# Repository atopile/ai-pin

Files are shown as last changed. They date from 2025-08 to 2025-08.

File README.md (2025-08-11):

## AI Pin — Your private, wearable memory

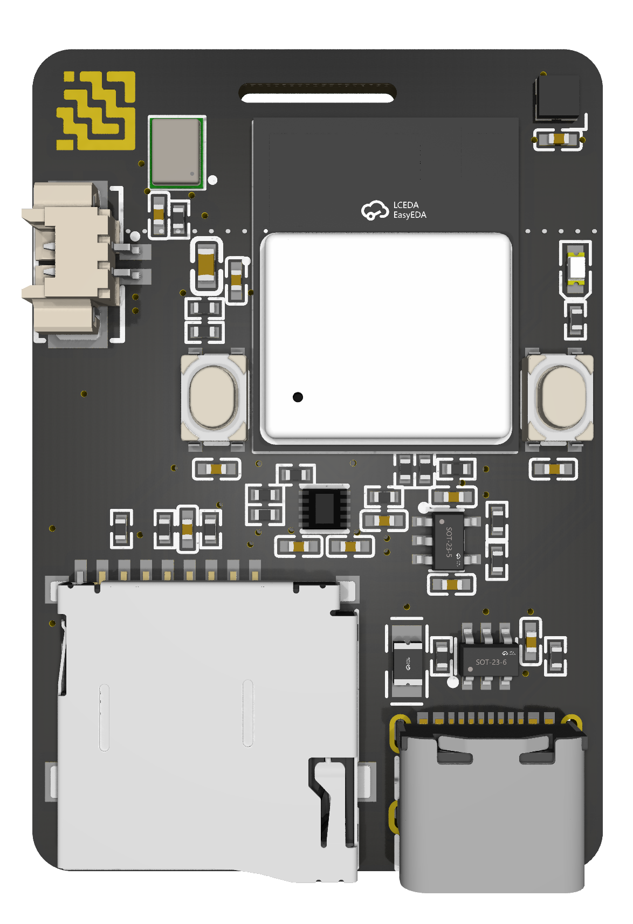
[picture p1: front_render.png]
AI Pin front render


**Stop forgetting what matters.** AI Pin is a privacy‑first wearable that captures your conversations throughout the day, then—when you’re home—offloads to your own local server to transcribe and make everything searchable. Ask, “What did I promise Alex yesterday?” or “What did I get done today?” and get instant answers from your own life.

### Why this is different

- **AI‑designed hardware**: The PCB is designed using `atopile` (a declarative electronics DSL) and lives as code in `ai-pin.ato`.
- **Local‑first by default**: All storage, transcription, embeddings and search run on your own machine—no cloud or third‑party services.
- **End‑to‑end system**: Wearable capture → local ingestion → Whisper transcription → vector search → Q&A and daily summaries.

### What it does

- **Continuous or on‑demand capture** via an I2S MEMS mic, storing audio on microSD.
- **Nightly offload** over Wi‑Fi while charging to a local server (Docker Compose).
- **Local transcription** using Whisper (GPU if available, CPU fallback).
- **Search & recall** across transcripts with semantic + keyword search.
- **Daily digest** of your day’s conversations and key moments.

### Moments you’ll stop forgetting

- “What did I promise to follow up on in today’s meeting?”
- “Who did I meet at the event—and what did we agree to do next?”
- “Which book/podcast did Sam recommend at lunch?”
- “What were the price, dates, and address the contractor mentioned?”
- “Where did we leave off on that debugging thread last week?”
- “What did the coach say about pickup changes for tomorrow?”
- “What’s the Wi‑Fi password/door code they told me?”
- “What exact phrasing did I use when I committed to that deliverable?”
- “What were the three ideas I said I’d write down later?”

---

## Architecture

```mermaid
graph TD
  Wearable["ESP32‑C3 AI Pin<br/>I2S mic → microSD (WAV)"] -->|Wi‑Fi offload| API[FastAPI Ingestion]
  API --> MINIO[(MinIO Object Storage)]
  API --> REDIS[(Redis Queue)]
  REDIS --> WORKER[Whisper Worker]
  MINIO --> WORKER
  WORKER --> MINIO
  WORKER --> DB[(Postgres + pgvector)]
  UI[Search & Daily Digest UI] --> API
  API --> DB
```

### Processing flow (upload → answer)

```mermaid
sequenceDiagram
    participant Dev as Device
    participant API as Ingestion API
    participant S3 as MinIO
    participant Q as Redis Queue
    participant W as Whisper Worker
    participant DB as Postgres/pgvector

    Dev->>API: POST /v1/upload (WAV)
    API->>S3: putObject(wav)
    API->>Q: enqueue({ key, device_id })
    W-->>Q: blpop()
    Q-->>W: { key, device_id }
    W->>S3: getObject(wav)
    W->>W: transcribe (Whisper)
    W->>S3: putObject(txt/json)
    W->>DB: upsert chunks + embeddings
    Note over W,DB: hybrid index: BM25 + vector
    UI->>API: /v1/search?q=...&time=...
    API->>DB: retrieve + rank
    API-->>UI: results/snippets
```

### Hardware (designed in code)

- MCU: ESP32‑C3 Mini‑1 (`I2S`, `SPI`, `Wi‑Fi`)
- Mic: TDK InvenSense ICS‑43434 (digital I2S)
- Storage: microSD over SPI
- Power: USB‑C → BQ25185 charger/power‑path → LDO (3.3 V)
- Battery: LP402535 (configurable)

See `ai-pin.ato` for the complete, declarative hardware design.

### Firmware (Zephyr RTOS)

- I2S capture → ring buffer → WAV writer (5–10 min segments)
- FATFS on SPI microSD, crash‑safe finalize, sidecar metadata
- Wi‑Fi offload window while charging; TLS upload
- Simple UX: LED states and a single button

### Local backend (Docker Compose)

- Ingestion API (FastAPI)
- Object storage (MinIO)
- Database (Postgres + pgvector)
- Queue (Redis)
- Transcription worker (Whisper via `faster-whisper`)

---

## Agents and your private history

You can point a local agent at your private transcripts to answer questions and automate tasks—without sending data to the cloud.

- **Local‑only by default**: Retrieval happens against your local DB/object store. No outbound calls unless you enable them.
- **Hybrid retrieval**: BM25 + vector search with time filters and device/user scoping.
- **Defensive prompts**: The API returns citations and timestamps; agents are encouraged to include them in answers.

Planned Agent API (local):

- `GET /v1/search` – hybrid search over transcripts
- `POST /v1/agents/query` – higher‑level query that returns stitched context windows for LLMs
- `POST /v1/agents/sessions` – create a scoped session with time/person/topic constraints

Example (planned) search call:

```bash
curl "http://localhost:8080/v1/search?q=what+did+I+promise+Alex&from=2025-01-01&to=2025-01-31&top_k=10"
```

Privacy boundaries:

- Local network only; bind to loopback or LAN per your `.env`.
- API tokens for agent clients; optional mTLS.
- Audit log of queries; per‑user/device scoping.
- Optional redaction layer (emails, credit cards) before indexing.

---

## Quickstart

### 1) Start the local stack

Create `backend/compose/.env` with these defaults (edit as needed):

```env
API_HOST=0.0.0.0
API_PORT=8080

MINIO_ENDPOINT=minio:9000
MINIO_ACCESS_KEY=minio
MINIO_SECRET_KEY=minio12345
MINIO_SECURE=false
MINIO_BUCKET=aipin

REDIS_URL=redis://redis:6379/0
WHISPER_MODEL=small
WHISPER_COMPUTE_TYPE=auto
```

Then launch:

```bash
cd backend/compose
docker compose up -d
```

Services:

- API: `http://localhost:8080`
- MinIO console: `http://localhost:9001` (user: `minio`, pass: `minio12345`)
- Postgres: `localhost:5432`
- Redis: `localhost:6379`

Health check:

```bash
curl http://localhost:8080/healthz
```

### 2) Upload a sample WAV (simulating the device)

```bash
curl -X POST \
  -F "device_id=test-device" \
  -F "file=@/path/to/sample.wav;type=audio/wav" \
  http://localhost:8080/v1/upload
```

The worker will pick it up, transcribe, and write a `.txt` next to the `.wav` in MinIO.

---

## Developing the firmware (ESP32‑C3 + Zephyr)

See detailed instructions in `firmware/zephyr/README.md`. Quickstart:

Prereqs (one‑time):

```bash
/opt/homebrew/bin/python3 -m venv "$HOME/zephyr-venv"
source "$HOME/zephyr-venv/bin/activate"
pip install -U pip west
cd "$HOME/zephyrproject"
export ZEPHYR_SDK_INSTALL_DIR="$HOME/zephyr-sdk-0.17.2"
export ZEPHYR_TOOLCHAIN_VARIANT=zephyr
west zephyr-export
```

Build & flash:

```bash
source "$HOME/zephyr-venv/bin/activate"
cd "$HOME/zephyrproject"
west build -b esp32c3_devkitm $(pwd -P)/../projects/ai-pin/firmware/zephyr/app -p always -- \
  -DDTC_OVERLAY_FILE=boards/esp32c3_devkitm.overlay \
  -DPython3_EXECUTABLE="$HOME/zephyr-venv/bin/python" -DWEST_PYTHON="$HOME/zephyr-venv/bin/python"
west flash
```

Provision Wi‑Fi on SD card (root):

```ini
ssid=YOUR_SSID
psk=YOUR_PASSWORD
```

Troubleshooting highlights:

- Missing blobs for ESP32: `west blobs fetch hal_espressif`
- I2S DMA error: ensure overlay enables `&dma { status = "okay"; }` and `&i2s { dmas = <&dma 0>, <&dma 1>; }`, and `CONFIG_DMA=y` in `prj.conf`
- CMake can’t find west: pass venv python flags shown above

---

## Project status

- Hardware captured in `ai-pin.ato` (Atopile)
- Backend Compose stack scaffolded: API + MinIO + Postgres + Redis + Whisper worker
- Firmware stubs prepared (Zephyr app structure)

See `spec.md` and `todo.md` for detailed scope, milestones, and open questions.

---

## Roadmap (MVP highlights)

- End‑to‑end ingest → transcribe
- Daily summary generation
- OTA updates via MCUboot
- Optional SD encryption and mTLS device identity

---

## Contributing

Issues and PRs welcome. The goal is a great local‑first reference design for private, wearable memory.

---

## License

MIT

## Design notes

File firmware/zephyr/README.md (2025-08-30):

# Firmware (Zephyr, ESP32‑C3)

This directory will contain the Zephyr application for the AI Pin firmware.

Quickstart

- Ensure you have a Zephyr workspace (e.g., `~/zephyrproject`) and Zephyr SDK installed (e.g., `~/zephyr-sdk-0.17.2`).
- This app targets ESP32‑C3 DevKitM and uses a device‑tree overlay to enable I2S and SPI SD (CS on GPIO4).

Environment setup (recommended once)

```
# Create/use a Python venv for west/cmake integration
/opt/homebrew/bin/python3 -m venv "$HOME/zephyr-venv"
source "$HOME/zephyr-venv/bin/activate"
pip install -U pip west

# Use your Zephyr workspace and SDK
cd "$HOME/zephyrproject"
export ZEPHYR_SDK_INSTALL_DIR="$HOME/zephyr-sdk-0.17.2"
export ZEPHYR_TOOLCHAIN_VARIANT=zephyr
west zephyr-export
```

Build

```
source "$HOME/zephyr-venv/bin/activate"
cd "$HOME/zephyrproject"
west build -b esp32c3_devkitm /Users/nicholaskrstevski/github/ai_pin/firmware/zephyr/app -p always -- \
  -DDTC_OVERLAY_FILE=boards/esp32c3_devkitm.overlay
```

Flash

```
west flash
```

Notes

- `prj.conf` enables I2S, SPI, FATFS, Wi‑Fi, Logging, and Settings. DMA is enabled for I2S.
- `boards/esp32c3_devkitm.overlay` maps SPI microSD CS to GPIO4 and enables I2S (`&i2s`). Update MOSI/MISO/SCLK to match your board.
- Wi‑Fi provisioning: copy `firmware/zephyr/wifi.txt.example` to the SD card root and rename to `wifi.txt`:
  - `ssid=YourNetwork`
  - `psk=YourPassword`
    The firmware reads `/SD:/wifi.txt` at boot and attempts to connect.

Troubleshooting

- If build fails to find west from CMake: pass the venv python
  - Add to the build command tail: `-DPython3_EXECUTABLE="$HOME/zephyr-venv/bin/python" -DWEST_PYTHON="$HOME/zephyr-venv/bin/python"`
- If blobs missing for ESP32: run `west blobs fetch hal_espressif` in `~/zephyrproject`.
- If you see "DMA peripheral is not enabled!" from I2S: ensure `CONFIG_DMA=y` and `CONFIG_DMA_ESP32=y` are set in `prj.conf`.
- For FatFS volume errors: use `zephyr,sdhc-spi-slot` with `mmc { compatible = "zephyr,sdmmc-disk"; }` in the overlay. Avoid hard‑coding `FS_FATFS_VOLUME_STRS` in `prj.conf`.

Run & monitor

- UART 115200‑8‑N‑1. Example: `screen /dev/tty.usbserial* 115200`
- Expected boot logs:
  - `AI Pin firmware (Zephyr) booting`
  - SD: `Mounted FAT at /SD:` (when card present)
  - Wi‑Fi: `Read Wi‑Fi credentials ...` then `Got IPv4 address`

Testing checklist (abridged)

- Build & flash: no immediate errors on boot
- Audio: no persistent I2S errors; ring overflows rare at idle
- Storage: `.wav` files in SD root; valid PCM S16LE @ 16kHz; rotation works
- Wi‑Fi: connects using `/SD:/wifi.txt` and obtains IPv4 address

## Monitoring serial output

Use one of the following options to view logs at 115200 baud.

Option A: west monitor (recommended if west is in your venv PATH)

```
source "$HOME/zephyr-venv/bin/activate"
cd "$HOME/zephyrproject"
west espressif monitor -p /dev/cu.usbmodem1101 -b 115200
# Quit with: Ctrl-]
```

Option B: Python miniterm (no west required)

```
python -m serial.tools.miniterm /dev/cu.usbmodem1101 115200
# Quit with: Ctrl-]
```

Option C: screen (preinstalled on macOS)

```
screen /dev/cu.usbmodem1101 115200
# Quit with: Ctrl-A then K, then Y
```

## Troubleshooting serial

- If you see only ROM boot messages and no Zephyr logs, the port may be reset into bootloader. Try another app that does not toggle DTR/RTS, such as miniterm or screen.
- If `west` is not found, ensure your venv is active: `source "$HOME/zephyr-venv/bin/activate"` and that west is installed: `pip install -U west` then `west --version`.
- To list ports: `ls /dev/cu.*` and pick the `usbmodem` (ESP32-C3 USB CDC) device.

## Expected boot logs

- `AI Pin firmware (Zephyr) booting`
- `Mounted FAT at /SD:` once the SD card is detected
- `Read Wi‑Fi credentials ...` then `Got IPv4 address` on successful Wi‑Fi

## Pinout (current build)

Note: Console is routed to on‑chip USB CDC; I2S is currently disabled to avoid SPI2 pin conflicts.

| Function | GPIO | Notes |
| --- | --- | --- |
| LED (red) | 20 | Active‑high heartbeat |
| Addressable LED (SK6805/WS2812) | 21 | Data‑in |
| SPI2 SCLK | 6 | Board `spim2_default` |
| SPI2 MOSI | 7 | Board `spim2_default` |
| SPI2 MISO | 2 | Board `spim2_default` |
| microSD CS | 4 | Active‑low (overlay `cs-gpios`)  |
| Console | USB CDC | `&usb_serial` (no external pins) |

## I2S mapping (disabled)

If I2S is enabled on this board configuration, pins map as:

- I2S MCLK: GPIO6
- I2S WS/LRCLK: GPIO5
- I2S BCLK: GPIO4
- I2S SD Out (to DAC): GPIO18
- I2S SD In (from mic): GPIO19

Conflict note: I2S BCLK on GPIO4 conflicts with the SD CS on GPIO4, and MCLK on GPIO6 conflicts with SPI2 SCLK on GPIO6. That’s why I2S is disabled in the current overlay.

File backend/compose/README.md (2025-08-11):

# Backend – Local testing guide

Start services

```bash
cd /Users/narayanpowderly/projects/ai-pin/backend/compose
docker compose up -d --build
docker compose ps
docker compose logs -f api worker
```

Health check

```bash
curl http://localhost:8080/healthz
```

Prepare test audio

- Convert MP3 to 16 kHz mono WAV (recommended):

```bash
ffmpeg -i /path/to/song.mp3 -ar 16000 -ac 1 /tmp/test.wav
```

- Or generate a 5s tone:

```bash
ffmpeg -f lavfi -i "sine=frequency=1000:duration=5" -ar 16000 -ac 1 /tmp/test.wav
```

Upload file to API

- WAV:

```bash
curl -X POST \
  -F "file=@/tmp/test.wav;type=audio/wav" \
  -F "device_id=dev123" \
  http://localhost:8080/v1/upload
```

- MP3:

```bash
curl -X POST \
  -F "file=@/path/to/song.mp3;type=audio/mpeg" \
  -F "device_id=dev123" \
  http://localhost:8080/v1/upload
```

Watch transcription progress

```bash
docker compose logs -f worker
```

Inspect artifacts in MinIO

- Console: http://localhost:9001 (user: `minio`, pass: `minio12345`), bucket: `aipin`
- With AWS CLI:

```bash
export AWS_ACCESS_KEY_ID=minio
export AWS_SECRET_ACCESS_KEY=minio12345
aws --endpoint-url http://localhost:9000 s3 ls s3://aipin/ --recursive
# Download transcript (replace KEY):
aws --endpoint-url http://localhost:9000 s3 cp s3://aipin/KEY .
```

Troubleshooting

```bash
docker compose ps
docker compose logs api
docker compose restart api
```

- Re-run upload and tail worker logs:

```bash
docker compose logs -f worker
```

Stop services

```bash
docker compose down
```

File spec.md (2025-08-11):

## AI Pin – Product & Technical Specification

### Summary

- Wearable device that captures audio throughout the day, stores locally on microSD, and offloads via Wi‑Fi to a private, user‑hosted server while charging. The local server transcribes audio to text with Whisper and makes it searchable for questions like “What did I get done today?”.

### Goals

- Reliable audio capture with minimal user interaction
- Nightly/private offload and transcription
- Local‑first: all data and processing live on the user’s own machine/NAS/server (no cloud dependency)
- Searchable, privacy‑respecting archive with daily summaries

### Non‑Goals (initially)

- On‑device transcription (server‑side only)
- Cellular connectivity
- Complex display/UI (stick to LED/haptics/buttons)

---

## Hardware (current design per `ai-pin.ato`)

### Bill of Materials (logical)

- MCU/Radio: `ESP32_C3_MINI_1_driver` (ESP32‑C3 module)
- USB Power/Connector: `USB2_0TypeCHorizontalConnector`
- Charger/Power Path: `BQ25185_driver`
- Primary Regulators: `LDK220M_R` (LDO to 3.3 V)
- Battery: `EMB_BATTERY_LP402535_driver` (configured 300 mAh)
- Microphone: `TDK_InvenSense_ICS_43434` (digital I2S MEMS MIC)
- Storage: `MicroSDCardAssemblyWithRemovableSPI` (microSD over SPI, CS on `mcu.gpio[4]`)
- I2C: pull‑ups 10 kΩ (0402) to `power_3v3`

### Power Topology

- `usb_c.usb.usb_if.buspower` → `power_vbus_5v`
- `power_vbus_5v` → `charger.power_vbus`
- Battery rail: `battery.power` ↔ `power_batt` ↔ `charger.power_batt`
- System rail: `charger.power_sys` → `LDK220M_R` → `power_3v3` (asserted 2.97–3.15 V)
- Loads: `mcu.power`, `mic.power`, `microsd.power` tied to `power_3v3`

### Digital Interfaces

- Audio: `mcu.i2s ~ mic.i2s`
- Storage: `mcu.spi ~ microsd.spi`, `mcu.gpio[4] ~ microsd.spi_cs`
- I2C: pull‑ups to 3.3 V; `mcu.i2c.sda.reference.hv ~> R ~> mcu.i2c.sda.line` and same for SCL

### Notes & Risks

- ESP32‑C3 performance/pins are sufficient for SPI microSD + I2S mic recording to WAV; consider throughput testing and SD card class requirements.
- Unresolved package imports currently reported by the toolchain; see “Ato package checklist”.

### Ato package checklist (to install)

- `atopile/espressif-esp32-c3/esp32_c3_mini.ato`
- `atopile/usb-connectors/usb-connectors.ato`
- `atopile/st-ldk220/st-ldk220.ato`
- `atopile/microphones/tdk_invensense_ics_43434.ato`
- `atopile/ti-bq25185/ti-bq25185.ato`
- `atopile/sd-card/sd-card-slots.ato`
- `atopile/batteries/eemb_battery_lp402535.ato`

---

## Firmware (ESP32‑C3, Zephyr RTOS)

### Core Features

- Audio capture via Zephyr I2S API → ring buffer → WAV chunking
- File I/O to SPI microSD using Zephyr `fs` (FATFS) with safe rotation and metadata sidecars
- Wi‑Fi provisioning and nightly offload to a local server with TLS (mTLS optional)
- LED/haptics/button UX for recording, charging, syncing, errors
- Power management (charger state, low‑battery shutdown)
- OTA update via MCUboot (image management with mcumgr over BLE/Wi‑Fi or HTTP OTA)

### Concurrency Model

- Zephyr threads and work queues
- Audio thread: configure I2S, optional VAD, double‑buffer
- Storage thread: consume buffers, write `.wav`, fsync, rotate N minutes
- Uploader thread: Wi‑Fi connect, scan for pending files, resume, checksum verify
- Power management: charger/ADC polling, battery state, thermal guardrails
- Provisioning: BLE or SoftAP captive portal; credentials via Zephyr Settings subsystem
- LED/UI: state machine driving RGB LED patterns; debounced button via Zephyr input APIs

### File/Format

- WAV PCM mono, 16 kHz, 16‑bit (Whisper friendly)
- Segment duration: 5–10 min; filename includes RTC + monotonic seq
- Sidecar JSON per file: { timestamp range, dropped frames, battery %, gain, sw/hw versions }

### Reliability & Security

- Preallocation/atomic rename on close; journal index for recovery
- Backpressure policy: pause capture if SD stalls; telemetry counter
- TLS 1.2+ to server; optional per‑file encryption (ChaCha20‑Poly1305) with device key stored via Zephyr Settings (and optional hardware keying later)

### UX Mapping (proposed)

- Button: short press start/stop recording; long press enters provisioning/sync
- LED: recording (solid red), idle (dim cyan), uploading (blue pulse), charging (amber), full (green), error (red blink), mute (magenta)
- Optional haptic buzz on state change

---

## Offload & Backend (Local‑first)

### Ingestion

- Authenticated upload endpoint (token or mTLS) hosted on the user’s machine/NAS/server. Supports resumable uploads and metadata posting.
- Stores raw audio + sidecars to local object storage (MinIO):
  - `users/{userId}/devices/{deviceId}/{YYYY}/{MM}/{DD}/{HHmmss}_{seq}.wav`
  - matching `.json` and `.txt` (post‑transcription)

### Processing

- Local queue per uploaded file (e.g., Redis)
- Local transcription workers using Whisper (e.g., `faster-whisper`). Language auto‑detect; VAD prepass to skip silence. No cloud services required.
- Post‑processing: sentence boundary alignment, optional diarization, timestamps

### Storage & Search

- Local Postgres for metadata and transcripts (JSONB per chunk)
- Local pgvector for embeddings; alternatives: local Qdrant/Milvus if scale dictates
- RAG pipeline: hybrid search (BM25 + vector) with time filters and user constraints

### Query UX

- Daily digest: “What did I get done today?” generated from that day’s transcripts
- Free‑form Q&A over selected time ranges

### Security & Privacy (backend)

- LAN‑only by default (no Internet egress needed); optional remote access via user‑managed reverse proxy/VPN
- TLS everywhere; encrypted local volumes; MinIO with server‑side encryption; per‑user isolation
- Audit logging; retention controls; deletion handling
- Optional PII redaction pass on transcripts

### Local deployment

- Provide a `docker-compose.yml` that brings up: API (FastAPI/Express), MinIO, Postgres (+pgvector), Redis, and a Whisper worker (GPU‑accelerated if available; CPU fallback)
- mDNS for local discovery; device posts to `https://ai-pin.local` (configurable)

### Agents & Private History

Local agents can query transcripts to answer questions and automate tasks without leaving your machine.

#### Retrieval model

- Hybrid search: BM25 + vector with reciprocal rank fusion; time and device filters
- Chunking: sentence or ~512‑token windows with overlap; store timestamps per chunk
- Embeddings: local model (e.g., `bge-small-en`) stored in pgvector; optional Qdrant/Milvus at scale

#### Agent sessions & scopes

- Session object defines time window, people/topics (optional), device/user scope, and privacy level
- Responses include citations (file key, start/end timestamps) for traceability
- Redaction profile can be applied per session before returning text to agents

#### Agent API (planned)

- `GET /v1/search` – hybrid search over transcripts with filters and `top_k`
- `POST /v1/agents/query` – returns stitched context windows for LLMs plus citations
- `POST /v1/agents/sessions` – create session with scope and redaction policy; returns `session_id`

#### Data model additions (planned)

- `agent_sessions(id, user_id, created_at, scope_json, redaction_profile)`
- `search_logs(id, session_id?, query, filters_json, top_k, latency_ms, created_at)`

#### Privacy & security defaults

- Bind API to loopback or LAN; no egress by default
- PAT or mTLS for agent clients; per‑user isolation
- Optional PII redaction before indexing and/or at query time
- Retention policies and deletion propagate to vector store and MinIO

---

## Data Model (sketch)

### Objects

- Audio: `.wav` in object storage; sidecars `.json`; transcripts `.txt` or JSON

### Database (Postgres)

- `users(id, email, created_at, ...)`
- `devices(id, user_id, model, public_key?, created_at, ...)`
- `files(id, device_id, path, start_ts, end_ts, duration_s, size_bytes, checksum, status, created_at)`
- `transcript_chunks(id, file_id, start_ms, end_ms, text, confidence, speaker?)`
- `embeddings(id, chunk_id, vector, model, created_at)`
- `jobs(id, type, status, payload, created_at, updated_at)`

---

## Security & Provisioning

- Device identity: token provisioned via BLE/SoftAP portal; optional per‑device cert (mTLS)
- On‑device keys via Zephyr Settings; secure boot/flash encryption can be enabled in later revisions
- SD at‑rest encryption optional (configurable per user)

---

## Milestones

- v0 Bench Prototype
  - ESP32‑C3 dev board + I2S mic + SPI microSD
  - Record WAV, manual Wi‑Fi upload, basic server endpoint
- v1 MVP Wearable
  - Custom PCB (this design), nightly offload, server transcription, searchable UI, OTA
- v2 Reliability/Privacy
  - Encryption at rest, device provisioning flow, improved power telemetry
- v3 UX & ML
  - Advanced Q&A, diarization, mobile companion app

---

## Acceptance Criteria (MVP)

- 8+ hours of continuous recording on 300 mAh battery or clear segmented/on‑demand mode documented
- <1% dropped audio frames per hour on a Class 10 microSD (specified test card)
- Nightly offload completes for a full day’s data over WPA2 network with retry
- End‑to‑end transcription and searchable queries over last 7 days
- OTA update succeeds and is roll‑back safe

---

## Implementation Options & Trade‑offs

- Mic: I2S MEMS (simple, low BOM) vs analog mic + codec (higher fidelity, more power/complexity)
- SD: SPI (fewer pins, slower) vs SDMMC 4‑bit (faster, more pins)
- Encryption: on‑device per‑file (privacy, CPU/battery cost) vs server‑only
- Provisioning: BLE (mobile‑friendly) vs SoftAP (no app, clunkier UX)
- Vector store: pgvector (simple ops) vs Qdrant/Milvus (scale)

---

## Open Questions

### Hardware

- Keep ESP32‑C3 or upgrade to S3 for USB‑OTG and more I2S headroom?
- Confirm ICS‑43434 mic orientation/porting and mechanical acoustics (wind/noise filters)?
- SPI microSD performance: required write throughput, target SD class, acceptable latency spikes?
- Include a fuel gauge (e.g., MAX17048) for better battery UX, or estimate via voltage?
- Add hardware mute switch for mic? LED behavior when muted?
- Charging LED behaviors and power‑path current limits for record‑while‑charge?

### Firmware

- Continuous recording vs VAD‑triggered segments to save space/power?
- Segment length: 5 vs 10 minutes vs silence‑aligned segments?
- On‑device file encryption from day one or later?
- Provisioning method: BLE vs SoftAP; do we ship a mobile app?
- Minimum acceptable dropped‑frame rate under worst‑case SD latency?
- Exact LED/haptic state machine definitions and timeouts?

### Backend/ML

- Transcription: Whisper locally (`faster-whisper`, choose model size per hardware); target accuracy vs local compute constraints?
- Embeddings: local (`bge-small-en` or similar) vs hosted; default is local‑only
- Vector DB: pgvector vs Qdrant/Milvus; expected daily transcript volume and 1‑year scale?
- PII handling/redaction requirements and default retention window?
- Query UX: chat‑style vs daily digest first; which user interfaces (web/mobile)?

### Security/Operations

- Device auth: token vs mTLS; key rotation strategy?
- SD at‑rest encryption: key provisioning, backup, and device‑loss UX?
- Wi‑Fi credential rotation and multi‑SSID support?
- OTA cadence, staged rollout, and failure recovery policy?

---

## Test Plan (high level)

- Throughput: validate continuous write of 16‑kHz 16‑bit mono WAV with <1% drops over 8 h
- Power: measure battery life in continuous vs VAD modes; thermals while charging + recording
- Filesystem: abrupt power‑loss tests; index recovery; file integrity checksums
- Networking: upload retries, resume support, checksum verification; TLS certificate validation to local server
- Backend: local queue backlog handling, transcription latency, accuracy sampling; measure CPU/GPU utilization
- Search: relevance on benchmark queries; time‑range filters; daily digest quality

---

## Next Steps

- Resolve Ato package imports and build PCB draft (hardware is largely done)
- Scaffold Zephyr application (I2S capture, FATFS on SPI SD, Wi‑Fi manager, TLS uploader, LED/button, Zephyr Settings)
- Create `docker-compose.yml` for local stack (API, MinIO, Postgres+pgvector, Redis, Whisper worker)
- Implement ingestion API and local Whisper worker
- Minimal web UI for daily summaries and free‑form questions

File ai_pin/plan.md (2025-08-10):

# AI Pin PCBA – Planning Document

This plan outlines the architecture, chosen packages, and key design decisions for an ESP32-C3 based “AI pin” with an I2S microphone, microSD storage, LiPo battery power with USB‑C charging, and a regulated 3.1 V rail for the MCU.

## Goals and constraints
- ESP32‑C3 microcontroller as main MCU
- Digital microphone for voice commands (I2S preferred)
- External microSD card for audio storage (SPI interface)
- Battery powered (single‑cell LiPo)
- USB‑C for charging and power
- Power path: either battery or USB 5 V feeds an LDO set to 3.1 V to supply the ESP32
- Follow `@.cursor/rules/how_to_build_packages.mdc`; use registry packages; build must be error‑free
- Do NOT implement code yet; this file is the plan to review before implementation

## Selected atopile packages (registry)
- MCU: `atopile/espressif-esp32-c3@0.1.4`
  - Use `ESP32_C3_MINI_1_driver` (compact module, good community support)
  - Provides `power`, `i2c`, `spi`, `i2s`, `gpio[N]` interfaces; example pin mux in README
- Microphone: `atopile/microphones@0.2.0`
  - Pick I2S mic: `TDK_InvenSense_ICS_43434`
  - Supply 1.62–3.6 V (OK at 3.1 V)
- microSD card: `atopile/sd-card@0.1.6` + socket `atopile/sd-card-slots@0.1.4`
  - Use SPI mode with ESP32‑C3 `spi` interface
  - VDD 2.7–3.6 V; 3.1 V is within spec
- USB‑C connector: `atopile/usb-connectors@0.3.0`
  - Use `USB2_0TypeCHorizontal_driver` (or vertical if preferred)
  - Exposes VBUS and USB2.0 D+/D- if needed
- Charger with power‑path: `atopile/ti-bq25185@0.1.0`
  - Single‑cell Li‑ion charger with power path; I2C control/status
  - Input from USB‑C VBUS; battery to BAT; system rail from charger goes to LDO input
- LDO (adjustable to 3.1 V): `atopile/st-ldk220@0.2.1`
  - 200 mA low‑IQ LDO; input up to 13.2 V; dropout 100–350 mV
  - Configure output via assertion to 3.1 V (+/‑ 5%)

## Power architecture
- `power_vbus_5v`: from USB‑C VBUS (5 V)
- `power_batt`: single‑cell LiPo (nominal ~3.7 V; 3.0–4.2 V range)
- `charger_power_path_out`: system rail from `BQ25185` (sourced from VBUS or battery via charger’s power path)
- `power_3v1`: LDO output set to 3.1 V (feeds logic and MCU)

Connections (conceptual):
- USB‑C VBUS → BQ25185 VIN
- LiPo (via 2‑pin battery connector, see below) → BQ25185 BAT
- BQ25185 system/power‑path output → LDK220M_R input
- LDK220M_R output (3.1 V) → ESP32‑C3 power, microphone power, microSD VDD, I2C pull‑ups, etc.

Notes:
- 3.1 V is chosen to reduce MCU power while keeping peripherals in spec (microSD 2.7–3.6 V, I2S mic 1.62–3.6 V)
- If battery drops below (3.1 V + LDO dropout), rail will fall out of regulation; plan brown‑out threshold accordingly in firmware

## Interfaces and routing
- I2S Microphone
  - `i2s ~ microphone.i2s`
  - Route `i2s.ws`, `i2s.sck`, `i2s.sd` per ESP32‑C3 pin mux (see driver README example)
  - Mic power from 3.1 V
- microSD over SPI
  - `spi ~ sd.spi` and one GPIO for `cs`
  - VDD from 3.1 V; ensure adequate decoupling and short traces
  - Consider small series resistors (22–33 Ω) on SPI lines if needed (SI integrity)
- I2C bus (for charger config/telemetry; optional other sensors later)
  - `i2c ~ charger.i2c`
  - Add pull‑ups to 3.1 V (10 kΩ 0402 typical); the ESP32‑C3 example shows a pattern for this
- USB data (optional)
  - If desired for CDC/DFU, connect USB D+/D- from connector to MCU USB interface (ESP32‑C3 supports native USB‑CDC on some SKUs). Not strictly required for MVP; serial flashing also possible via UART.

## Connectors and passives
- Battery connector: JST‑PH‑2 (2.0 mm) or JST‑SH‑2 (1.0 mm) for compactness
  - If no registry package exists, use a simple 2‑pin connector package later; wire to BQ25185 BAT/GND
- Power rail decoupling
  - Follow each package recommendations; ensure local 100 nF near each IC, plus bulk caps near LDO output and charger input
- Pull‑ups / bias
  - I2C: 2× 10 kΩ to 3.1 V (SDA/SCL)
  - Charger: check BQ25185 pin requirements (ILIM, STAT, EN, thermistor/NTC). Driver likely models these; otherwise add passives per datasheet.

## Current budget (rough)
- ESP32‑C3 active wifi/BT: 80–240 mA peaks (depends on mode)
- I2S mic: a few mA
- microSD active write: 50–100 mA peaks
- LDO LDK220 limit: 200 mA — Risk: may be insufficient during simultaneous Wi‑Fi peaks + SD activity
  - Mitigations:
    - Reduce RF TX power / duty cycling
    - Switch to higher‑current LDO if needed (alternative regulator TBD)
    - Use local bulk capacitance on 3.1 V rail to absorb transients

## Software‑visible constraints
- Run ESP32 at 3.1 V; ensure brown‑out detector set appropriately (~2.9–3.0 V)
- SPI clock to SD tuned for stable operation at 3.1 V and board trace lengths
- I2S sample rate and mic gain set in firmware
- Charger configuration via I2C: set charge current per chosen battery and USB constraints

## Open questions / risks
- LDO headroom vs. ESP32 + SD peaks: 200 mA may be tight → be ready to swap for higher‑current LDO if needed
- Exact ESP32‑C3 module variant (Mini‑1 vs WROOM‑02): Mini‑1 is planned; verify antenna keepout and footprint
- Battery selection and connector footprint (capacity, discharge rate)
- microSD slot mechanical choice (push‑push vs push‑pull; top vs bottom mount)
- Do we expose USB D+/D- to ESP32 for CDC/flashing?
- BQ25185 details: confirm the driver’s power‑path output node to use for the LDO input; validate NTC/ILIM pins handling

## Implementation plan (after approval)
1. Create `ai_pin/ai-pin.ato` top‑level module
2. Install packages:
   - `atopile add atopile/espressif-esp32-c3`
   - `atopile add atopile/microphones`
   - `atopile add atopile/sd-card`
   - `atopile add atopile/sd-card-slots`
   - `atopile add atopile/usb-connectors`
   - `atopile add atopile/ti-bq25185`
   - `atopile add atopile/st-ldk220`
3. Wire power tree: USB‑C → BQ25185 → LDO → 3.1 V rail → loads
4. Wire I2S mic, SPI SD, I2C to charger; add pull‑ups
5. Add decoupling caps per package guidance
6. Build and resolve compiler/LSP issues; iterate on pin mux and constraints
7. Review DRC/ERC; refine footprints and mechanical choices

## Acceptance checklist prior to coding
- Package set agreed
- 3.1 V rail confirmed acceptable for ESP32, mic, and SD
- Current budget acceptable or alternative LDO identified
- Decision on USB data connectivity
- Battery capacity and connector style chosen

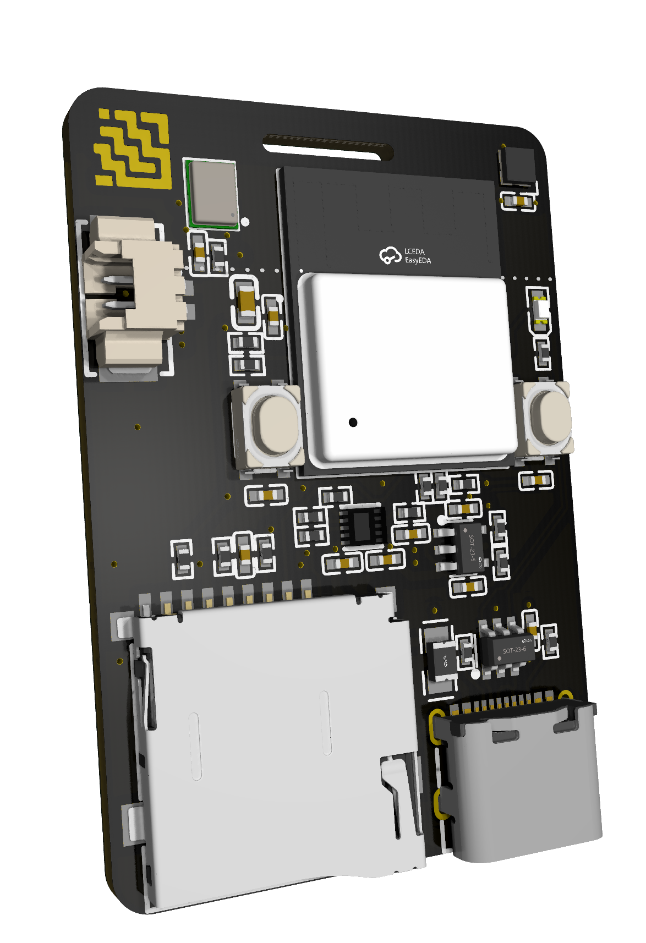
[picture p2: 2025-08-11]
tilt_render.png

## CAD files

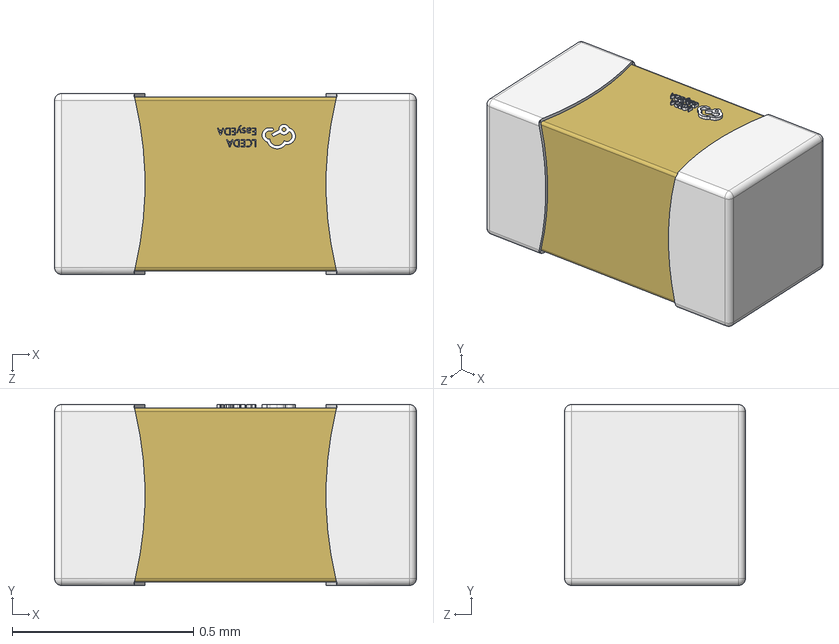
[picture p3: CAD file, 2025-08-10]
parts/Murata_Electronics_GRM155R60J106ME44D/C0402_L1.0-W0.5-H0.5.step
1.00 x 0.5 x 0.5 mm

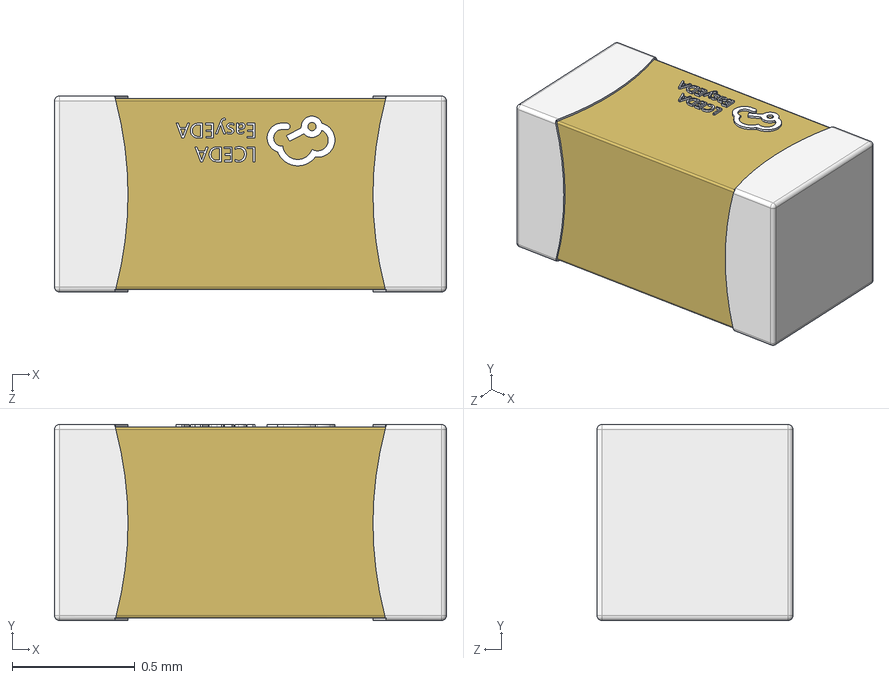
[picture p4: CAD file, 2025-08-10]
parts/Samsung_Electro_Mechanics_CL10A226MQ8NRNC/C0603_L1.6-W0.8-H0.8.step
1.60 x 0.8 x 0.8 mm

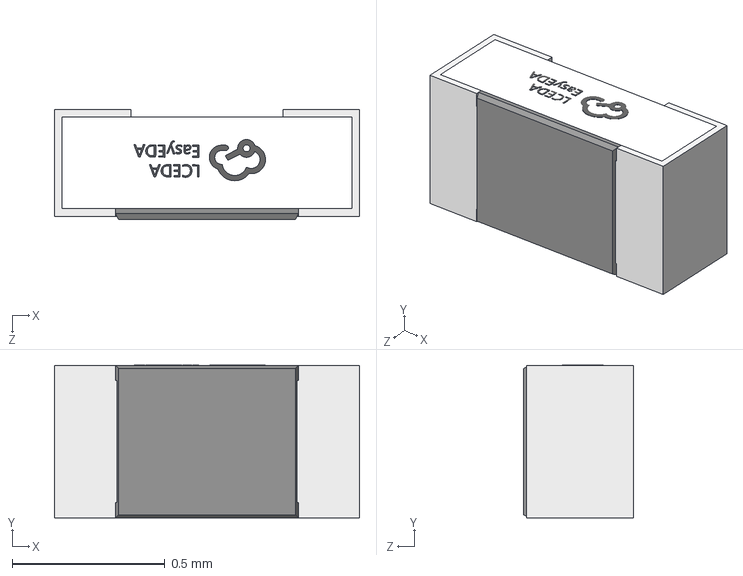
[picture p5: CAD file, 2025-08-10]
parts/YAGEO_RC0402FR_076K2L/R0402_L1.0-W0.5-H0.4.step
1.00 x 0.501 x 0.36 mm

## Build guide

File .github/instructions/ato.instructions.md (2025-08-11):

---
description: ato is a declarative DSL to design electronics (PCBs) with.
applyTo: *.ato, ato.yaml
---

ato is a declarative DSL to design electronics (PCBs) with.
It is part of the atopile project.
Atopile is run by the vscode/cursor/windsurf extension.
The CLI (which is invoked by the extension) actually builds the project.

# Not available in ato

- if statements
- while loops
- functions (calls or definitions)
- classes
- objects
- exceptions
- generators

# Ato Syntax

ato sytax is heavily inspired by Python, but fully declarative.
ato thus has no procedural code, and no side effects.

## Examples of syntax

```ato
#pragma text
#pragma func("X")
# enable for loop syntax feature:
#pragma experiment("FOR_LOOP)

# --- Imports ---
# Standard import (newline terminated)
import ModuleName

# Import with multiple modules (newline terminated)
import Module1, Module2.Submodule

# Import from a specific file/source (newline terminated)
from "path/to/source.ato" import SpecificModule

# Multiple imports on one line (semicolon separated)
import AnotherModule; from "another/source.ato" import AnotherSpecific

# Deprecated import form (newline terminated)
# TODO: remove when unsupported
import DeprecatedModule from "other/source.ato"

# --- Top-level Definitions and Statements ---

pass
pass;

"docstring-like statement"
"docstring-like statement";

top_level_var = 123

# Compound statement
pass; another_var = 456; "another docstring"

# Block definitions
component MyComponent:
    # Simple statement inside block (newline terminated)
    pass

    # Multiple simple statements on one line (semicolon separated)
    pass; internal_flag = True

module AnotherBaseModule:
    pin base_pin
    base_param = 10

interface MyInterface:
    pin io

module DemoModule from AnotherBaseModule:
    # --- Declarations ---
    pin p1              # Pin declaration with name
    pin 1               # Pin declaration with number
    pin "GND"           # Pin declaration with string
    signal my_signal    # Signal definition
    a_field: AnotherBaseModule      # Field declaration with type hint

    # --- Assignments ---
    # Newline terminated:
    internal_variable = 123

    # Semicolon separated on one line:
    var_a = 1; var_b = "string"

    # Cumulative assignment (+=, -=) - Newline terminated
    value = 1
    value += 1; value -= 1

    # Set assignment (|=, &=) - Newline terminated
    flags |= 1; flags &= 2

    # --- Connections ---
    p1 ~ base_pin
    mif ~> bridge
    mif ~> bridge ~> bridge
    mif ~> bridge ~> bridge ~> mif
    bridge ~> mif
    mif <~ bridge
    mif <~ bridge <~ bridge
    mif <~ bridge <~ bridge <~ mif
    bridge <~ mif

    # Semicolon separated on one line:
    p_multi1 ~ my_signal; p_multi2 ~ sig_multi1

    # --- Retyping ---
    instance.x -> AnotherBaseModule

    # --- Instantiation ---
    instance = new MyComponent
    container = new MyComponent[10]
    templated_instance_a = new MyComponent
    templated_instance_b = new MyComponent<int_=1>
    templated_instance_c = new MyComponent<float_=2.5>
    templated_instance_d = new MyComponent<string_="hello">
    templated_instance_e = new MyComponent<int_=1, float_=2.5, string_="hello">
    templated_instance_f = new MyComponent<int_=1, float_=2.5, string_="hello", bool_=True>

    # Semicolon separated instantiations (via assignment):
    inst_a = new MyComponent; inst_b = new AnotherBaseModule

    # --- Traits ---
    trait trait_name
    trait trait_name<int_=1>
    trait trait_name<float_=2.5>
    trait trait_name<string_="hello">
    trait trait_name<bool_=True>
    trait trait_name::constructor
    trait trait_name::constructor<int_=1>

    # Semicolon separated on one line:
    trait TraitA; trait TraitB::constructor; trait TraitC<arg_=1>

    # --- Assertions ---
    assert x > 5V
    assert x < 10V
    assert 5V < x < 10V
    assert x >= 5V
    assert x <= 10V
    assert current within 1A +/- 10mA
    assert voltage within 1V +/- 10%
    assert resistance is 1kohm to 1.1kohm

    # Semicolon separated on one line:
    assert x is 1V; assert another_param is 2V

    # --- Loops ---
    for item in container:
        item ~ p1

    # For loop iterating over a slice
    for item in container[0:4]:
        pass
        item.value = 1; pass

    # For loop iterating over a list literal of field references
    for ref in [p1, x.1, x.GND]:
        pass

    # --- References and Indexing ---
    # Reference with array index assignment
    array_element = container[3]

    # --- Literals and Expressions ---
    # Integer
    int_val = 100
    neg_int_val = -50
    hex_val = 0xF1
    bin_val = 0b10
    oct_val = 0o10
    # Float
    float_val = 3.14
    # Physical quantities
    voltage: V = 5V
    resistance: ohm = 10kohm
    capacitance: F = 100nF
    # Bilateral tolerance
    tolerance_val = 1kohm +/- 10%
    tolerance_abs = 5V +/- 500mV
    tolerance_explicit_unit = 10A +/- 1A
    # Bounded quantity (range)
    voltage_range = 3V to 3.6V
    # Boolean
    is_enabled = True
    is_active = False
    # String
    message = "Hello inside module"

    # Arithmetic expressions
    sum_val = 1 + 2
    diff_val = 10 - 3ohm
    prod_val = 5 * 2mA
    div_val = 10V / 2kohm # Results in current
    power_val = 2**3
    complex_expr = (5 + 3) * 2 - 1
    flag_check = state | MASK_VALUE

    # Comparisons
    assert voltage within voltage_range
    assert length <= 5mm
    assert height >= 2mm

# --- Multi-line variations ---
pass; nested_var=1; another=2

complex_assignment = (
    voltage + resistance
    * capacitance
)

```

## G4 Grammar

```g4
parser grammar AtoParser;

options {
	superClass = AtoParserBase;
	tokenVocab = AtoLexer;
}

file_input: (NEWLINE | stmt)* EOF;

pragma_stmt: PRAGMA;

stmt: simple_stmts | compound_stmt | pragma_stmt;
simple_stmts:
	simple_stmt (SEMI_COLON simple_stmt)* SEMI_COLON? NEWLINE;
simple_stmt:
	import_stmt
	| dep_import_stmt
	| assign_stmt
	| cum_assign_stmt
	| set_assign_stmt
	| connect_stmt
	| directed_connect_stmt
	| retype_stmt
	| pin_declaration
	| signaldef_stmt
	| assert_stmt
	| declaration_stmt
	| string_stmt
	| pass_stmt
	| trait_stmt;

compound_stmt: blockdef | for_stmt;

blockdef: blocktype name blockdef_super? COLON block;
// TODO @v0.4 consider ()
blockdef_super: FROM type_reference;
// TODO @v0.4 consider removing component (or more explicit code-as-data)
blocktype: (COMPONENT | MODULE | INTERFACE);
block: simple_stmts | NEWLINE INDENT stmt+ DEDENT;

// TODO: @v0.4 remove the deprecated import form
dep_import_stmt: IMPORT type_reference FROM string;
import_stmt: (FROM string)? IMPORT type_reference (
		COMMA type_reference
	)*;

declaration_stmt: field_reference type_info;
field_reference_or_declaration:
	field_reference
	| declaration_stmt;
assign_stmt: field_reference_or_declaration '=' assignable;
cum_assign_stmt:
	field_reference_or_declaration cum_operator cum_assignable;
// TODO: consider sets cum operator
set_assign_stmt:
	field_reference_or_declaration (OR_ASSIGN | AND_ASSIGN) cum_assignable;
cum_operator: ADD_ASSIGN | SUB_ASSIGN;
cum_assignable: literal_physical | arithmetic_expression;

assignable:
	string
	| new_stmt
	| literal_physical
	| arithmetic_expression
	| boolean_;

retype_stmt: field_reference ARROW type_reference;

directed_connect_stmt
	: bridgeable ((SPERM | LSPERM) bridgeable)+; // only one type of SPERM per stmt allowed. both here for better error messages
connect_stmt: mif WIRE mif;
bridgeable: connectable;
mif: connectable;
connectable: field_reference | signaldef_stmt | pindef_stmt;

signaldef_stmt: SIGNAL name;
pindef_stmt: pin_stmt;
pin_declaration: pin_stmt;
pin_stmt: PIN (name | number_hint_natural | string);

new_stmt: NEW type_reference ('[' new_count ']')? template?;
new_count: number_hint_natural;

string_stmt:
	string; // the unbound string is a statement used to add doc-strings

pass_stmt:
	PASS; // the unbound string is a statement used to add doc-strings

list_literal_of_field_references:
	'[' (field_reference (COMMA field_reference)* COMMA?)? ']';

iterable_references:
	field_reference slice?
	| list_literal_of_field_references;

for_stmt: FOR name IN iterable_references COLON block;

assert_stmt: ASSERT comparison;

trait_stmt
	: TRAIT type_reference (DOUBLE_COLON constructor)? template?; // TODO: move namespacing to type_reference
constructor: name;
template: '<' (template_arg (COMMA template_arg)* COMMA?)? '>';
template_arg: name ASSIGN literal;

// Comparison operators --------------------
comparison: arithmetic_expression compare_op_pair+;

compare_op_pair:
	lt_arithmetic_or
	| gt_arithmetic_or
	| lt_eq_arithmetic_or
	| gt_eq_arithmetic_or
	| in_arithmetic_or
	| is_arithmetic_or;

lt_arithmetic_or: LESS_THAN arithmetic_expression;
gt_arithmetic_or: GREATER_THAN arithmetic_expression;
lt_eq_arithmetic_or: LT_EQ arithmetic_expression;
gt_eq_arithmetic_or: GT_EQ arithmetic_expression;
in_arithmetic_or: WITHIN arithmetic_expression;
is_arithmetic_or: IS arithmetic_expression;

// Arithmetic operators --------------------

arithmetic_expression:
	arithmetic_expression (OR_OP | AND_OP) sum
	| sum;

sum: sum (PLUS | MINUS) term | term;

term: term (STAR | DIV) power | power;

power: functional (POWER functional)?;

functional: bound | name '(' bound+ ')';

bound: atom;

// Primary elements ----------------

slice:
	'[' (slice_start? COLON slice_stop? (COLON slice_step?)?)? ']'
	// else [::step] wouldn't match
	| '[' ( DOUBLE_COLON slice_step?) ']';
slice_start: number_hint_integer;
slice_stop: number_hint_integer;
slice_step: number_hint_integer;

atom: field_reference | literal_physical | arithmetic_group;

arithmetic_group: '(' arithmetic_expression ')';

literal_physical:
	bound_quantity
	| bilateral_quantity
	| quantity;

bound_quantity: quantity TO quantity;
bilateral_quantity: quantity PLUS_OR_MINUS bilateral_tolerance;
quantity: number name?;
bilateral_tolerance: number_signless (PERCENT | name)?;

key: number_hint_integer;
array_index: '[' key ']';

// backwards compatibility for A.1
pin_reference_end: DOT number_hint_natural;
field_reference_part: name array_index?;
field_reference:
	field_reference_part (DOT field_reference_part)* pin_reference_end?;
type_reference: name (DOT name)*;
// TODO better unit
unit: name;
type_info: COLON unit;
name: NAME;

// Literals
literal: string | boolean_ | number;

string: STRING;
boolean_: TRUE | FALSE;
number_hint_natural: number_signless;
number_hint_integer: number;
number: (PLUS | MINUS)? number_signless;
number_signless: NUMBER;
```

# Most used library modules/interfaces (api of them)

```ato
interface Electrical:
    pass

interface ElectricPower:
    hv = new Electrical
    lv = new Electrical

module Resistor:
    resistance: ohm
    max_power: W
    max_voltage: V
    unnamed = new Electrical[2]

module Capacitor:
    capacitance: F
    max_voltage: V
    unnamed = new Electrical[2]

interface I2C:
    scl = new ElectricLogic
    sda = new ElectricLogic
    frequency: Hz
    address: dimensionless

interface ElectricLogic:
    line = new Electrical
    reference = new ElectricPower
```

For the rest use the atopile MCP server 
- `get_library_interfaces` to list interfaces
- `get_library_modules` to list modules
- `inspect_library_module_or_interface` to inspect the code

# Ato language features

## experimental features

Enable with `#pragma experiment("BRIDGE_CONNECT")`
BRIDGE_CONNECT: enables `p1 ~> resistor ~> p2` syntax
FOR_LOOP: enables `for item in container: pass` syntax
TRAITS: enables `trait trait_name` syntax
MODULE_TEMPLATING: enables `new MyComponent<param=literal>` syntax

## modules, interfaces, parameters, traits

A block is either a module, interface or component.
Components are just modules for code-as-data.
Interfaces describe a connectable interface (e.g Electrical, ElectricPower, I2C, etc).
A module is a block that can be instantiated.
Think of it as the ato equivalent of a class.
Parameters are variables for numbers and they work with constraints.
E.g `resistance: ohm` is a parameter.
Constrain with `assert resistance within 10kohm +/- 10%`.
It's very important to use toleranced values for parameters.
If you constrain a resistor.resistance to 10kohm there won't be a single part found because that's a tolerance of 0%.

Traits mark a module to have some kind of functionality that can be used in other modules.
E.g `trait has_designator_prefix` is the way to mark a module to have a specific designator prefix that will be used in the designator field in the footprint.

## connecting

You can only connect interfaces of the same type.
`resistor0.unnamed[0] ~ resistor0.unnamed[0]` is the way to connect two resistors in series.
If a module has the `can_bridge` trait you can use the sperm operator `~>` to bridge the module.
`led.anode ~> resistor ~> power.hv` connects the anode in series with the resistor and then the resistor in series with the high voltage power supply.

## for loop syntax

`for item in container: pass` is the way to iterate over a container.

# Ato CLI

## How to run

You run ato commands through the MCP tool.

## Packages

Packages can be found on the ato registry.
To install a package you need to run `ato add <PACKAGE_NAME>`.
e.g `ato install atopile/addressable-leds`
And then can be imported with `from "atopile/addressable-leds/sk6805-ec20.ato" import SK6805_EC20_driver`.
And used like this:

```ato
module MyModule:
    led = new SK6805_EC20_driver
```

## Footprints & Part picking

Footprint selection is done through the part choice (`ato create part` auto-generates ato code for the part).
The `pin` keyword is used to build footprint pinmaps so avoid using it outside of `component` blocks.
Preferrably use `Electrical` interface for electrical interfaces.
A lot of times it's actually `ElectricLogic` for things like GPIOs etc or `ElectricPower` for power supplies.

Passive modules (Resistors, Capacitors) are picked automatically by the constraints on their parameters.
To constrain the package do e.g `package = "0402"`.
To explictly pick a part for a module use `lcsc = "<LCSC_PART_NUMBER>"`.

# Creating a package

Package generation process:

Review structure of other pacakges.

1. Create new Directory in 'packages/packages' with naming convention '<vendor>-<device>' eg 'adi-adau145x'
2. create an ato.yaml file in the new directory with the following content:

```yaml
requires-atopile: '^0.9.0'

paths:
    src: '.'
    layout: ./layouts

builds:
    default:
        entry: <device>.ato:<device>_driver
    example:
        entry: <device>.ato:Example
```

3. Create part using tool call 'search_and_install_jlcpcb_part'
4. Import the part into the <device>.ato file
5. Read the datasheet for the device
6. Find common interfaces in the part eg I2C, I2S, SPI, Power

7. Create interfaces and connect them

power interfaces:
power*<name> = new ElectricPower
power*<name>.required = True # If critical to the device
assert power\*<name>.voltage within <minimum*operating_voltage>V to <maximum_operating_voltage>V
power*<name>.vcc ~ <device>.<vcc pin>
power\_<name>.gnd ~ <device>.<gnd pin>

i2c interfaces:
i2c = new I2C
i2c.scl.line ~ <device>.<i2c scl pin>
i2c.sda.line ~ <device>.<i2c sda pin>

spi interfaces:
spi = new SPI
spi.sclk.line ~ <device>.<spi sclk pin>
spi.mosi.line ~ <device>.<spi mosi pin>
spi.miso.line ~ <device>.<spi miso pin>

8. Add decoupling capacitors

looking at the datasheet, determine the required decoupling capacitors

eg: 2x 100nF 0402:

power_3v3 = new ElectricPower

# Decoupling power_3v3

power_3v3_caps = new Capacitor[2]
for capacitor in power_3v3_caps:
capacitor.capacitance = 100nF +/- 20%
capacitor.package = "0402"
power_3v3.hv ~> capacitor ~> power_3v3.lv

9. If device has pin configurable i2c addresses

If format is: <n x fixed address bits><m x pin configured address bits>
use addressor module:

- Use `Addressor<address_bits=N>` where **N = number of address pins**.
- Connect each `address_lines[i].line` to the corresponding pin, and its `.reference` to a local power rail.
- Set `addressor.base` to the lowest possible address and `assert addressor.address is i2c.address`.

10. Create a README.md

# <Manufacturer> <Manufacturer part number> <Short description>

## Usage

```ato
<copy in example>

```

## Contributing

Contributions to this package are welcome via pull requests on the GitHub repository.

## License

This atopile package is provided under the [MIT License](https://opensource.org/license/mit/).

11. Connect high level interfaces directly in example:

eg:

i2c = new I2C
power = new ElectricPower
sensor = new Sensor

i2c ~ sensor.i2c
power ~ sensor.power_3v3

# Additional Notes & Gotchas (generic)

- Multi-rail devices (VDD / VDDIO, AVDD / DVDD, etc.)

    - Model separate `ElectricPower` interfaces for each rail (e.g. `power_core`, `power_io`).
    - Mark each `.required = True` if the device cannot function without it, and add voltage assertions per datasheet.

- Optional interfaces (SPI vs I²C)

    - If the device supports multiple buses, pick one for the initial driver. Leave unused bus pins as `ElectricLogic` lines or expose a second interface module later.

- Decoupling guidance

    - If the datasheet shows multiple caps, model the **minimum required** set so the build passes; you can refine values/packages later.

- File / directory layout recap
    - `<vendor>-<device>/` – package root
    - `ato.yaml` – build manifest (include `default` **and** `example` targets)
    - `<device>.ato` – driver + optional example module
    - `parts/<MANUFACTURER_PARTNO>/` – atomic part + footprint/symbol/step files

These tips should prevent common "footprint not found", "pin X missing", and build-time path errors when you add new devices.

# Vibe coding a project

If the user gives you high level description of the project, use the following guide:

# How LLMs can design electronics:

#1 Rule: USE THE TOOLS. If the tools dont work, dont freak out, you are probably using them wrong. Ask for help if you get stuck.

Top level design

1. Research available packages relevant to the user requests using 'find_packages'
2. Inspect promising packages using 'inspect_package'
3. Propose packages to use for project and architucture to user, revise if needed
4. Install needed packages using 'install_package'
5. Import packages into main file
6. Create instances of packages in main module

## Power

1. Review for each package the required voltage and current (current may not be provided, use judement if nessesary)
2. Determine the power rails that need to be generated and a suitable tollerance (typically ~3-5% is acceptable)
3. Determine the input power source, typically a battery, USB connector or other power connector (eg XT30) and install relevant package
4. Find suitable regulators:
   a) if input voltage > required voltage and current is low, use an LDO package
   b) if input voltage > required voltage and current is high, use buck converter
   c) if input votlage < required voltage, use a boost converter
   d) if input voltage can be both less than or greater than input voltage, use buck boost (eg battery powered device that needs 3v3)
5. If battery powered, add charger package

Typical power architucture example with LDO:

- USB input power
- Low current output (eg microcontroller)

from "atopile/ti-tlv75901/ti-tlv75901.ato" import TLV75901_driver
from "atopile/usb-connectors/usb-connectors.ato" import USBCConn

module App:

    # Rails
    power_5v = new Power
    power_3v3 = new Power

    # Components
    ldo = new TLV75901_driver
    usb_connector = new USBCConn

    # Connections
    usb_connector.power ~ power_vbus
    power_vbus ~> ldo ~> power_3v3

## Communicaions

1. Review packages required interfaces, typically i2c, spi or ElectricLogics
2. Find suitable pins on the controller, typically a microcontroller or Linux SOC
3. Connect interfaces eg micro.i2c[0] ~ sensor.i2c

## Development process notes

- After making changes, be sure to use 'build_project' to update the PCB
- Builds will often generate errors/warnings, these should be reviewed and fixed
- Prioritize pacakges from 'atopile' over other packages

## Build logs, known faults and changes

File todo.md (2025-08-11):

## TODO – AI Pin (Zephyr firmware, local-first backend)

### MVP

#### Firmware (Zephyr, ESP32‑C3)

- [ ] Project scaffold
  - [ ] Create Zephyr app skeleton (board: ESP32‑C3; overlays for pins)
  - [ ] `prj.conf`: enable I2S, SPI, FATFS, Wi‑Fi, HTTP/TLS, Settings, Logging, MCUboot
  - [ ] DTS overlay: I2S mic, SPI microSD (CS on GPIO4), LED, button
- [ ] Audio capture & buffering
  - [ ] Configure I2S RX mono 16 kHz, 16‑bit
  - [ ] Ring buffer with drop counters; backpressure policy
  - [ ] WAV writer (RIFF headers, atomic finalize); 5–10 min rotation
- [ ] Sidecar JSON: timestamps, drops, versions
- [ ] Storage (microSD over SPI)
  - [ ] Mount FATFS; performance test with target SD class
  - [ ] Preallocation, fsync cadence; crash‑safe rename on close
  - [ ] Journaled file index and recovery on boot
- [ ] Networking & offload
  - [ ] Wi‑Fi manager (auto connect, backoff); NTP sync
- [ ] TLS uploader with token auth
  - [ ] Resumable/chunked uploads; checksum verification; retry/resume
  - [ ] SoftAP or BLE provisioning; persist creds via Settings
- [ ] UI & power
  - [ ] LED state machine (recording/idle/uploading/error)
  - [ ] Button handling (debounce; short/long press; provisioning)
  - [ ] Charger/fuel telemetry (ADC/charger IC); low‑battery shutdown
- [ ] OTA
  - [ ] Enable MCUboot; signed image update; rollback support
- [ ] Telemetry & logs
  - [ ] Persist counters

#### Backend (Local‑first; Docker Compose)

- [ ] Security
  - [ ] Optional per‑file SD encryption (ChaCha20‑Poly1305); key storage in Settings
  - [ ] Key rotation/wipe flow
- [ ] Telemetry & logs
  - [ ] Persist counters; optional log upload during offload window

### Backend (Local‑first; Docker Compose)

- [ ] Compose stack
  - [ ] Services: API, MinIO, Postgres(+pgvector), Redis, Whisper worker, optional Caddy (TLS)
  - [ ] Volumes, networks, `.env.sample` and defaults
- [ ] Ingestion API
  - [ ] Device registration + auth (PAT)
  - [ ] Resumable file uploads; checksum; metadata endpoint
  - [ ] mDNS discovery; LAN‑only default
- [ ] Processing
  - [ ] Whisper worker (faster‑whisper), CPU fallback (GPU if available)
  - [ ] Store transcript artifacts (.txt/.json)
- [ ] Storage & indexing
  - [ ] DB schema + migrations (users, devices, files, transcript_chunks, embeddings, jobs)
  - [ ] Embeddings pipeline (local model, e.g., bge‑small‑en); pgvector index
  - [ ] Background indexer and compaction
- [ ] Search & summaries
  - [ ] Query API (BM25+vector, time filters)
  - [ ] Minimal web UI (upload status, search, daily summary)
- [ ] Admin & ops
  - [ ] Metrics/health endpoints; dashboards
  - [ ] Retention/purge tools; backup scripts for MinIO/Postgres
  - [ ] TLS: self‑signed or Caddy-managed certs; device trust bootstrap

#### Testing & Validation (MVP)

- [ ] Firmware throughput/soak: 8 h continuous write, <1% drops on target SD
- [ ] Filesystem robustness: abrupt power loss, index recovery, integrity checksums
- [ ] Networking: retries, resume, TLS validation to local server
- [ ] Backend: queue handling, transcription latency, CPU utilization
- [ ] End‑to‑end: device → local API → transcription → search

##### Firmware Testing Plan (Zephyr, ESP32‑C3)

- [ ] Prereqs & setup

  - [ ] Hardware: ESP32‑C3 DevKitM (or your board), formatted microSD (FAT32), I2S MEMS mic wired per `esp32c3*.overlay`.
  - [ ] Create `wifi.txt` on SD root:
    ```ini
    ssid=YOUR_SSID
    psk=YOUR_PASSWORD
    ```
  - [ ] Connect UART and prepare a serial monitor (115200‑8‑N‑1). Example:
    ```bash
    screen /dev/tty.usbserial* 115200
    ```

- [ ] Build & flash smoke test

  - [ ] Build and flash:
    ```bash
    west build -b esp32c3_devkitm firmware/zephyr/app -p always
    west flash
    ```
  - [ ] On boot, confirm logs show: "AI Pin firmware booting" with no immediate errors.

- [ ] Audio capture (I2S → ring buffer)

  - [ ] Verify I2S config succeeds (no `i2s_configure` / `i2s start failed` errors).
  - [ ] Observe for `Audio ring overflow` warnings during silence and speech; occasional bursts are OK during bring‑up.
  - [ ] Acceptance: no persistent I2S errors; overflow warning rate low at idle; audio thread stays running.

- [ ] Storage (FATFS on SPI SD) and WAV correctness

  - [ ] Confirm FAT mounts (`Mounted FAT at /SD:` in logs). If SD is absent, insert and reboot.
  - [ ] Confirm `.wav` files appear in SD root; filenames are monotonic (ms timestamp).
  - [ ] Copy a segment to host and validate header:
    ```bash
    ffprobe -hide_banner -show_streams -select_streams a:0 /path/to/file.wav | cat
    ```
    - Expect PCM S16LE, 1 channel, 16000 Hz; duration ≈ segment length.
  - [ ] Segment rotation: temporarily set `segment_seconds = 10` (dev build) and confirm new file every 10 s.
  - [ ] Flush cadence: verify file grows and is synced roughly once per second (no massive loss after reset).
  - [ ] Crash‑safety: power‑cycle mid‑record; after reboot, last completed file remains valid; current file may be partial but header of previous file remains correct.

- [ ] Throughput & soak (target: <1% drops over 8 h)

  - [ ] Let device run 30–60 min, then 8 h, capturing UART logs to a file.
  - [ ] Compute drop ratio from logs: `sum(dropped_bytes) / total_bytes_written`.
    - Total bytes per second expected: `16000 * 1 * (16/8) = 32000 B/s`.
    - Acceptance: drop ratio < 1% over 8 h on target SD class.

- [ ] Wi‑Fi connect (credentials from SD)

  - [ ] Ensure `/SD:/wifi.txt` present; observe logs: `Read Wi‑Fi credentials ...`, then `Got IPv4 address` and `Wi‑Fi connected and IPv4 acquired` within ~20 s.
  - [ ] Negative: wrong password → `Wi‑Fi connect timeout` is logged; fix creds and confirm recovery after reboot.

- [ ] Optional diagnostics (when needed)

  - [ ] Enable Zephyr stack usage tracking to verify `MAIN_STACK_SIZE`, worker stacks are sufficient.
  - [ ] Add a compile‑time option to print bytes/sec written and ring buffer depth watermark.

- [ ] Firmware acceptance criteria
  - [ ] Device builds, flashes, and boots without errors.
  - [ ] WAV segments are valid PCM S16LE @ 16 kHz; rotation works at configured interval.
  - [ ] Crash during write does not corrupt previously finalized segments.
  - [ ] Over an 8 h soak, ring overflow implied drops < 1% (based on logs and file sizes).
  - [ ] Wi‑Fi connects with credentials from SD and reaches DHCP/IPv4 assignment.

##### Backend Testing Plan (API + Worker + MinIO + Redis)

- [ ] Automated unit tests

  - [ ] API: run `pytest -q` in `backend/api` (covers `/healthz`, upload happy‑path, and content‑type rejection)
  - [ ] Worker: run `pytest -q` in `backend/worker/whisper` (covers queue pop, MinIO read/write, and transcription glue)

- [ ] Integration tests (Docker Compose)

  - [ ] Start stack
    - [ ] `cd backend/compose && docker compose up -d`
    - [ ] Ensure `.env` matches defaults in `README.md` (`MINIO_*`, `REDIS_URL`, `WHISPER_*`).
  - [ ] Health checks
    - [ ] API: `curl http://localhost:8080/healthz` → `{ "status": "ok" }`
    - [ ] MinIO console reachable at `http://localhost:9001` (login: `minio` / `minio12345`)
    - [ ] Redis reachable at `localhost:6379`
  - [ ] Upload sample WAV (simulated device)
    - [ ] Create a 2s mono 16kHz WAV:
      ```bash
      ffmpeg -f lavfi -i anullsrc=channel_layout=mono:sample_rate=16000 -t 2 -c:a pcm_s16le sample.wav
      ```
    - [ ] Upload:
      ```bash
      curl -X POST \
        -F "device_id=test-device" \
        -F "file=@./sample.wav;type=audio/wav" \
        http://localhost:8080/v1/upload
      ```
    - [ ] Assert response includes `key`, `size_bytes > 0`, `enqueued: true`.
  - [ ] Verify object landed in MinIO
    - [ ] Via console: bucket `aipin` contains the uploaded `devices/test-device/YYYY/MM/DD/...wav` key.
  - [ ] Verify worker transcription
    - [ ] `docker compose logs -f worker | sed -n 's/.*done .* → .*\.txt.*/&/p' | head -n 1 | cat` shows completion for the key
    - [ ] MinIO contains adjacent `.txt` next to the uploaded `.wav` key; file non‑empty.

- [ ] Negative/edge cases

  - [ ] Unsupported content‑type: upload `text/plain` → API returns `415` (covered by tests)
  - [ ] Empty file: upload zero‑byte WAV → API accepts, MinIO stores, worker produces empty/near‑empty `.txt` (define expected behavior)
  - [ ] Large file (e.g., 50–100 MB): upload succeeds without API timeout; worker processes within reasonable time
  - [ ] Redis unavailable: simulate by stopping `redis`; upload should currently error (500). Capture and note expected behavior for future graceful‑degradation.
  - [ ] MinIO unavailable: simulate by stopping `minio`; upload should error (500). Confirm API surfaces failure clearly.

- [ ] Basic performance checks

  - [ ] Burst upload 10×2s WAVs (looped curl) → all enqueued; queue drains to zero within N seconds; `.txt` objects present for all keys
  - [ ] Measure end‑to‑end latency (upload → `.txt`) under idle conditions; record baseline

- [ ] Acceptance criteria
  - [ ] With the compose stack up, a WAV upload returns 200 and enqueues a job
  - [ ] The worker writes a non‑empty `.txt` next to the `.wav` in MinIO
  - [ ] Negative tests behave as specified above (415 for bad content‑type; clear 5xx on backend dependency failure)
  - [ ] All unit tests pass in both API and worker

### Later

#### Security & Privacy

- [ ] Threat model and data‑flow diagram
- [ ] Local‑only default; guidance for optional remote access (VPN/reverse proxy)
- [ ] Data export/delete; per‑user isolation; audit logging
- [ ] SD at‑rest encryption option; key provisioning and recovery plan

#### Additional Testing

- [ ] Power tests: battery life (continuous vs VAD), thermals while charging+recording
- [ ] Search relevance benchmarks; daily digest quality sampling

### Milestones

- [ ] v0 Bench Prototype
  - [ ] Record WAV to SD; manual upload to local API; server stores file
  - [ ] Manual transcription via worker script
- [ ] v1 MVP Wearable
  - [ ] Auto nightly upload; Whisper transcription; search UI; OTA
  - [ ] LED/button UX; provisioning; NTP; checksum & resume
- [ ] v2 Reliability/Privacy
  - [ ] SD encryption option; metrics/observability; improved battery UX
  - [ ] Signed updates; key rotation; retention tools

### Decisions Needed

- [ ] Provisioning method: BLE vs SoftAP (default?)
- [ ] SD encryption on by default? Key backup UX?
- [ ] Whisper model size(s) for worker (CPU‑only vs GPU‑capable)
- [ ] Embedding model (local) and vector store (pgvector vs Qdrant)

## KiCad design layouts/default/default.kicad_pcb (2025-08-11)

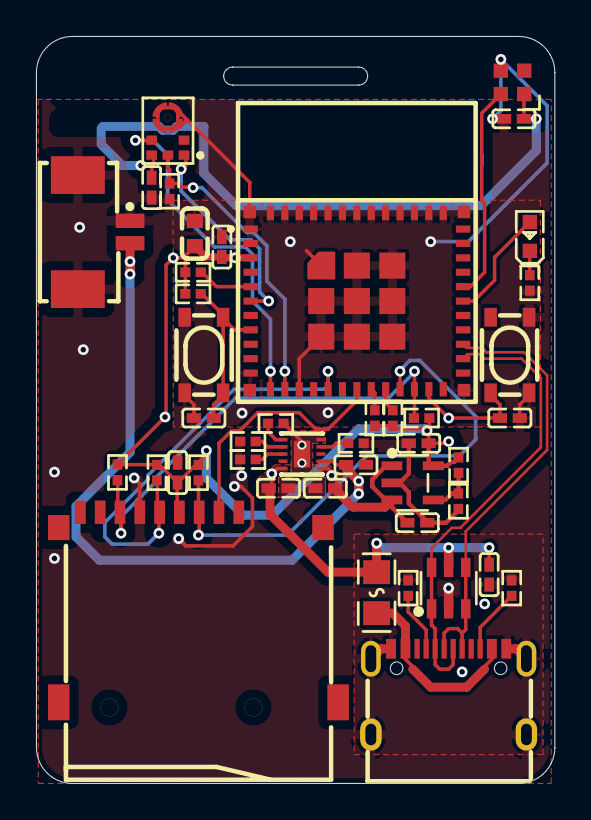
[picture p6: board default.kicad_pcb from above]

Board: 2 copper layers, 28.8 x 41.5 mm, 46 parts (1 on the bottom side), 31 nets.

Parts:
B1: EEMB_BATTERY_LP402535
C1, C2, C9, C11: 1µF ±10% 25V X5R; C0402
C3, C4, C6, C7, C8, C12, C13: 100nF ±10% 16V X7R; C0402
C5: 22µF ±20% 6.3V X5R; C0603
C10: 10µF ±20% 6.3V X5R; C0402
Card1: TF-SMD_TF-01A
D1: SOT-23-6_L2.9-W1.6-P0.95-LS2.8-BL
F1: F0805
LED1: LED-SMD_4P-L2.0-W2.0-BR
LED3: LED0603-RD
LOGO1: atopile_Logo_4x4mm
R1, R2, R3, R5, R6, R7, R11, R12, R14, R15, R16, R17, R19: 10kΩ ±1% 62.5mW; R0402
R4: 16kΩ ±1% 62.5mW; R0402
R8: 100kΩ ±1% 62.5mW; R0402
R9, R10: 5.1kΩ ±1% 62.5mW; R0402
R13: 18kΩ ±1% 62.5mW; R0402
SW1, SW2: KEY-SMD_4P-L4.2-W3.2-P2.20-LS4.6
U1: SOT-23-5_L3.0-W1.7-P0.95-LS2.8-BL
U2: WIFIM-SMD_ESP32-C3-MINI-1
U3: MIC-SMD_6P-L3.5-W2.7-P0.90-BL
U4: CONN-SMD_532610271
U5: WSON-10_L2.2-W2.0-P0.40-BL-EP_TI_DLH0010A
USB1: USB-C-SMD_TYPE-C-6PIN-2MD-073

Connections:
-hv-0: C9.1, U4.2, U5.2
-hv-1: C8.1, C11.1, D1.5, F1.2, U5.10
-line-0: LED1.4, U2.31
-line-1: R1.2, U2.19
-line-2: R2.2, U2.20
-line-3: U2.12, U3.4
-line-4: R8.1, U2.13, U3.6
-line-5: U2.6, U3.1
ADJ_NC: R3.1, R4.2, U1.4
GND: Card1.10, Card1.11, Card1.12, Card1.13
ILIM_VSET: R13.1, U5.7
ISET: R11.1, U5.8
SYS: C1.1, C10.1, U1.1, U1.3, U5.1
TS_MR: R17.1, U5.6
anode: LED3.2, U2.30
cathode: LED3.1, R19.1
gnd: C1.2, C2.2, C3.1, C4.1, C5.2, C6.2, C7.2, C8.2, C9.2, C10.2, C11.2, C12.2, C13.2, Card1.6, D1.2, LED1.3, R3.2, R8.2, R9.2, R10.2, R11.2, R12.2, R13.2, R17.2, R19.2, SW1.1, SW1.2, SW2.1, SW2.2, U1.2, U2.1, U2.2, U2.11, U2.14, U2.36, U2.37, U2.38, U2.39, U2.40, U2.41, U2.42, U2.43, U2.44, U2.45, U2.46, U2.47, U2.48, U2.49, U2.50, U2.51, U2.52, U2.53, U3.3, U4.1, U4.3, U4.4, U5.5, U5.11, USB1.1, USB1.12, USB1.13, USB1.14, USB1.15, USB1.16
hv-0: F1.1, USB1.2, USB1.11
hv-1: C2.1, C5.1, C6.1, C7.1, C12.1, C13.1, Card1.4, LED1.1, R1.1, R2.1, R4.1, R5.2, R6.2, R7.1, R14.2, R15.2, R16.2, U1.5, U2.3, U3.5
line-0: R9.1, USB1.4
line-1: R10.1, USB1.10
line-4: D1.1, D1.6, U2.26, USB1.5, USB1.7
line-5: D1.3, D1.4, U2.27, USB1.6, USB1.8
mcu-line: R5.1, U2.5
nCE: R12.1, U5.4
output-0: C3.2, SW1.3, SW1.4, U2.23
output-1: C4.2, R7.2, SW2.3, SW2.4, U2.8
sd_chip_select_1: Card1.2, U2.18
sd_clk: Card1.5, R16.1, U2.16
sd_miso: Card1.7, R6.1, R14.1, U2.22
sd_mosi: Card1.3, R15.1, U2.21

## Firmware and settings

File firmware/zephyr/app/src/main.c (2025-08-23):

// Core
#include <zephyr/kernel.h>
#include <zephyr/logging/log.h>

// Subsystems
#include "audio.h"
#include "storage.h"
#include "net.h"
#include "ui.h"

LOG_MODULE_REGISTER(ai_pin, LOG_LEVEL_INF);

static void start_workers(void)
{
    // storage_init();
    // audio_init();
    // net_init();
    ui_init();

    // storage_start();
    // audio_start();
}

int main(void)
{
    LOG_INF("AI Pin firmware (Zephyr) booting");

    start_workers();

    while (true)
    {
        ui_tick();
        k_sleep(K_MSEC(100));
    }
    return 0;
}

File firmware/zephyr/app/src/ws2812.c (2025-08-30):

#include <zephyr/kernel.h>
#include <zephyr/device.h>
#include <zephyr/drivers/gpio.h>
#include <zephyr/sys/time_units.h>
#include <zephyr/irq.h>

#include "ws2812.h"

#include <zephyr/logging/log.h>
LOG_MODULE_REGISTER(ws2812, LOG_LEVEL_INF);

/* GPIO21 per ai-pin.ato connection for addressable_led.data_in */
#define WS2812_GPIO_PIN 21

static const struct device *gpio_dev = DEVICE_DT_GET(DT_NODELABEL(gpio0));

// T1H 1 code ,high voltage time 0.8us ±150ns
// T1L 1 code ,low voltage time 0.45us ±150ns
// T0H 0 code ,high voltage time 0.4us ±150ns
// T0L 0 code , low voltage time 0.85us ±150ns

static inline void ws2812_nops(uint32_t n)
{
    for (volatile uint32_t i = 0; i < n; ++i)
    {
        __asm__ volatile ("nop");
    }
}

static void ws2812_write_byte(uint8_t b)
{
    for (int i = 7; i >= 0; --i)
    {
        bool bit = (b >> i) & 1;
        gpio_pin_set_raw(gpio_dev, WS2812_GPIO_PIN, 1);

        if (bit)
        {
            ws2812_nops(7);
            gpio_pin_set_raw(gpio_dev, WS2812_GPIO_PIN, 0);
            ws2812_nops(3);
        }
        else
        {
            ws2812_nops(2);
            gpio_pin_set_raw(gpio_dev, WS2812_GPIO_PIN, 0);
            ws2812_nops(8);
        }
    }
}

void ws2812_init(void)
{
    if (!device_is_ready(gpio_dev))
    {
        LOG_ERR("GPIO controller not ready");
        return;
    }
    int rc = gpio_pin_configure(gpio_dev, WS2812_GPIO_PIN, GPIO_OUTPUT);
    if (rc)
    {
        LOG_ERR("gpio_pin_configure failed: %d", rc);
        return;
    }
    LOG_INF("WS2812 GPIO initialized on pin %d", WS2812_GPIO_PIN);
    /* Ensure LED is off at boot and send a reset */
    gpio_pin_set_raw(gpio_dev, WS2812_GPIO_PIN, 0);
    k_busy_wait(300);
    /* Force LED completely off first */
    LOG_INF("Turning WS2812 OFF");
    ws2812_off();
    k_sleep(K_MSEC(100));
    /* Test with a simple red color to verify it's working */
    LOG_INF("Testing WS2812 with red color - you should see timing on scope");
    ws2812_set_rgb(255, 0, 0); /* Full brightness red for easier scope measurement */
    
    /* Send a test pattern for easier scope analysis */
    LOG_INF("Sending test pattern: 0xAA (alternating 1010 pattern)");
    for (int i = 0; i < 3; i++) {
        ws2812_write_byte(0xAA); /* 10101010 pattern for easy timing measurement */
    }
    gpio_pin_set_raw(gpio_dev, WS2812_GPIO_PIN, 0);
    k_busy_wait(80);
}

void ws2812_set_rgb(uint8_t r, uint8_t g, uint8_t b)
{
    if (!device_is_ready(gpio_dev))
        return;

    /* WS2812 expects GRB order */
    unsigned int key = irq_lock();
    ws2812_write_byte(g);
    ws2812_write_byte(r);
    ws2812_write_byte(b);
    /* Reset: hold low for >50us */
    gpio_pin_set_raw(gpio_dev, WS2812_GPIO_PIN, 0);
    k_busy_wait(80);
    irq_unlock(key);
}

void ws2812_off(void)
{
    ws2812_set_rgb(0, 0, 0);
}

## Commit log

2025-08-10 gpt5 building
    [C0402_L1.0-W0.5-H0.5.step, C0603_L1.6-W0.8-H0.8.step, R0402_L1.0-W0.5-H0.4.step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]
2025-08-10 layout done
    [R0402_L1.0-W0.5-H0.4.step, default.kicad_pcb]
2025-08-10 add nice logo
    [atopile_logo_25x25mm.kicad_pcb, atopile_logo_25x6mm.kicad_pcb, atopile_logo_4x4mm.kicad_pcb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]
2025-08-10 fix add usb comms connection
    [default.kicad_pcb]
2025-08-11 looking good
    [default.kicad_pcb]
2025-08-11 cleaning up readme
    [default.kicad_pcb]
2025-08-23 got bitbang addressable, some clock issue
    [main.c, ui.c, ws2812.c]
